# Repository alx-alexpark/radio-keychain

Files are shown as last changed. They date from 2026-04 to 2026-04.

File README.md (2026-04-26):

# radio-keychain
A fully-functional FM receiver in a 3x3cm footprint, perfect for a keychain.

It uses the connected headphones as an antenna, and is powered off a CR2032 coin cell. The FM tuner used is the Si4702, which supports the 76-108MHz frequency range.

Based on the CH32v003, this radio runs on RISC-V!

## Motivation
I love radio, and I wanted to make the tiniest keychain radio possible. I also thought it would be interesting to learn how radios work.

## How to use
First, connect a pair of headphones or an aux cable, this is your antenna. There are 4 buttons on the device, a volume up/down, and a frequency up/down. First, set the volume to a confortable level, and then use the frequency up/down buttons to step up and down 0.1MHz until you find a station. Then, enjoy listening to the station!

## Schematic and PCB
https://kicanvas.org/?repo=https://github.com/alx-alexpark/radio-keychain

## Zine
A5 - 1

## Bill of Materials

| Designator | Footprint | Quantity | Value | LCSC Part # |
|---|---|---|---|---|
| BT1 | BAT-SMD_MY-2032-12 | 1 | MY-2032-12 | [C964833](https://www.lcsc.com/product-detail/C964833.html) |
| C1, C6 | 0402 | 2 | 100nF | [C1525](https://www.lcsc.com/product-detail/C1525.html) |
| C2 | 0402 | 1 | 100pF | [C1546](https://www.lcsc.com/product-detail/C1546.html) |
| C3, C4 | 0603 | 2 | 0.47uF | [C1623](https://www.lcsc.com/product-detail/C1623.html) |
| C5, C7, C8 | 0603 | 3 | 1uF | [C1592](https://www.lcsc.com/product-detail/C1592.html) |
| C9 | 0402 | 1 | 22nF | [C1532](https://www.lcsc.com/product-detail/C1532.html) |
| CN1 | PJ-320D | 1 | PJ-320D | [C431535](https://www.lcsc.com/product-detail/C431535.html) |
| D1 | 0402 | 1 | LED | [C2286](https://www.lcsc.com/product-detail/C2286.html) |
| FB1, FB2 | 0603 | 2 | BLM18BD252SN1D | [C77668](https://www.lcsc.com/product-detail/C77668.html) |
| J1 | PinHeader_1x03_P2.54mm_Vertical | 1 | Conn_01x03_Pin | — |
| L1 | 0603 | 1 | LQW18ANR27J00D | [C98093](https://www.lcsc.com/product-detail/C98093.html) |
| OSC1 | CRYSTAL-SMD_4P-L3.2-W2.5-BL | 1 | SX2M32_768KM20F30TNN | [C2901603](https://www.lcsc.com/product-detail/C2901603.html) |
| R1, R2, R3, R4, R5, R6 | 0603 | 6 | 10k | [C25804](https://www.lcsc.com/product-detail/C25804.html) |
| R10, R9 | 0402 | 2 | 2k | [C4109](https://www.lcsc.com/product-detail/C4109.html) |
| R11 | 0402 | 1 | 330 | [C25104](https://www.lcsc.com/product-detail/C25104.html) |
| R7, R8 | 0402 | 2 | 2.2k | [C25879](https://www.lcsc.com/product-detail/C25879.html) |
| SW1, SW2, SW3, SW4 | SW-SMD_4P-L4.2-W3.3-P2.15-LS5.1 | 4 | SW_Push_45deg | [C455282](https://www.lcsc.com/product-detail/C455282.html) |
| SW5 | SW-SMD_MST22D18G2 | 1 | K3-2235S-F1 | [C223858](https://www.lcsc.com/product-detail/C223858.html) |
| U1 | QFN-20-1EP_3x3mm_P0.4mm_EP1.65x1.65mm | 1 | CH32V003F4U6 | [C5299908](https://www.lcsc.com/product-detail/C5299908.html) |
| U2 | QFN-28_4x4mm_P0.5mm | 1 | TPA6130A2RTJR | [C130046](https://www.lcsc.com/product-detail/C130046.html) |
| U3 | MPS_QFN-16_3x3mm_P0.5mm | 1 | SI4702-C19-GMR | [C2155666](https://www.lcsc.com/product-detail/C2155666.html) |

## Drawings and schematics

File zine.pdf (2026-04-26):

# Keychain Radio

### By Alex Park (18, TX)

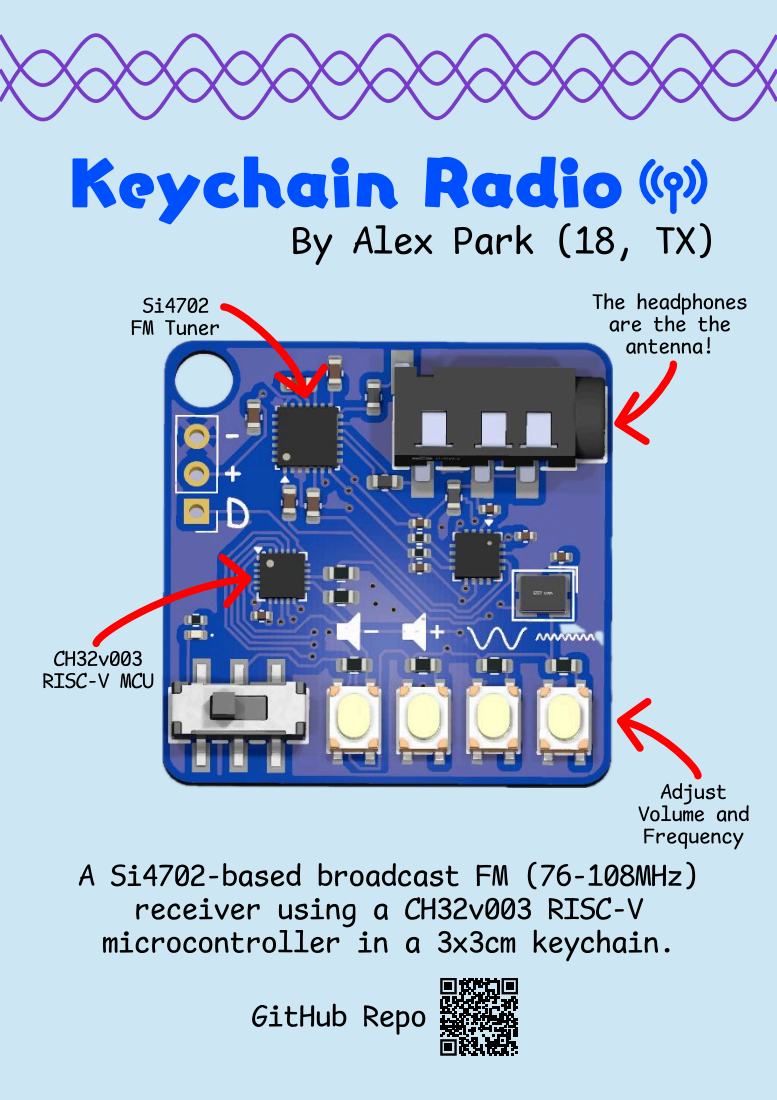
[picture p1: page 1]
Si4702 FM Tuner; CH32v003 RISC-V MCU; Adjust; Volume and Frequency; GitHub Repo

The headphones
are the the
antenna!

A Si4702-based broadcast FM (76-108MHz)
receiver using a CH32v003 RISC-V
microcontroller in a 3x3cm keychain.

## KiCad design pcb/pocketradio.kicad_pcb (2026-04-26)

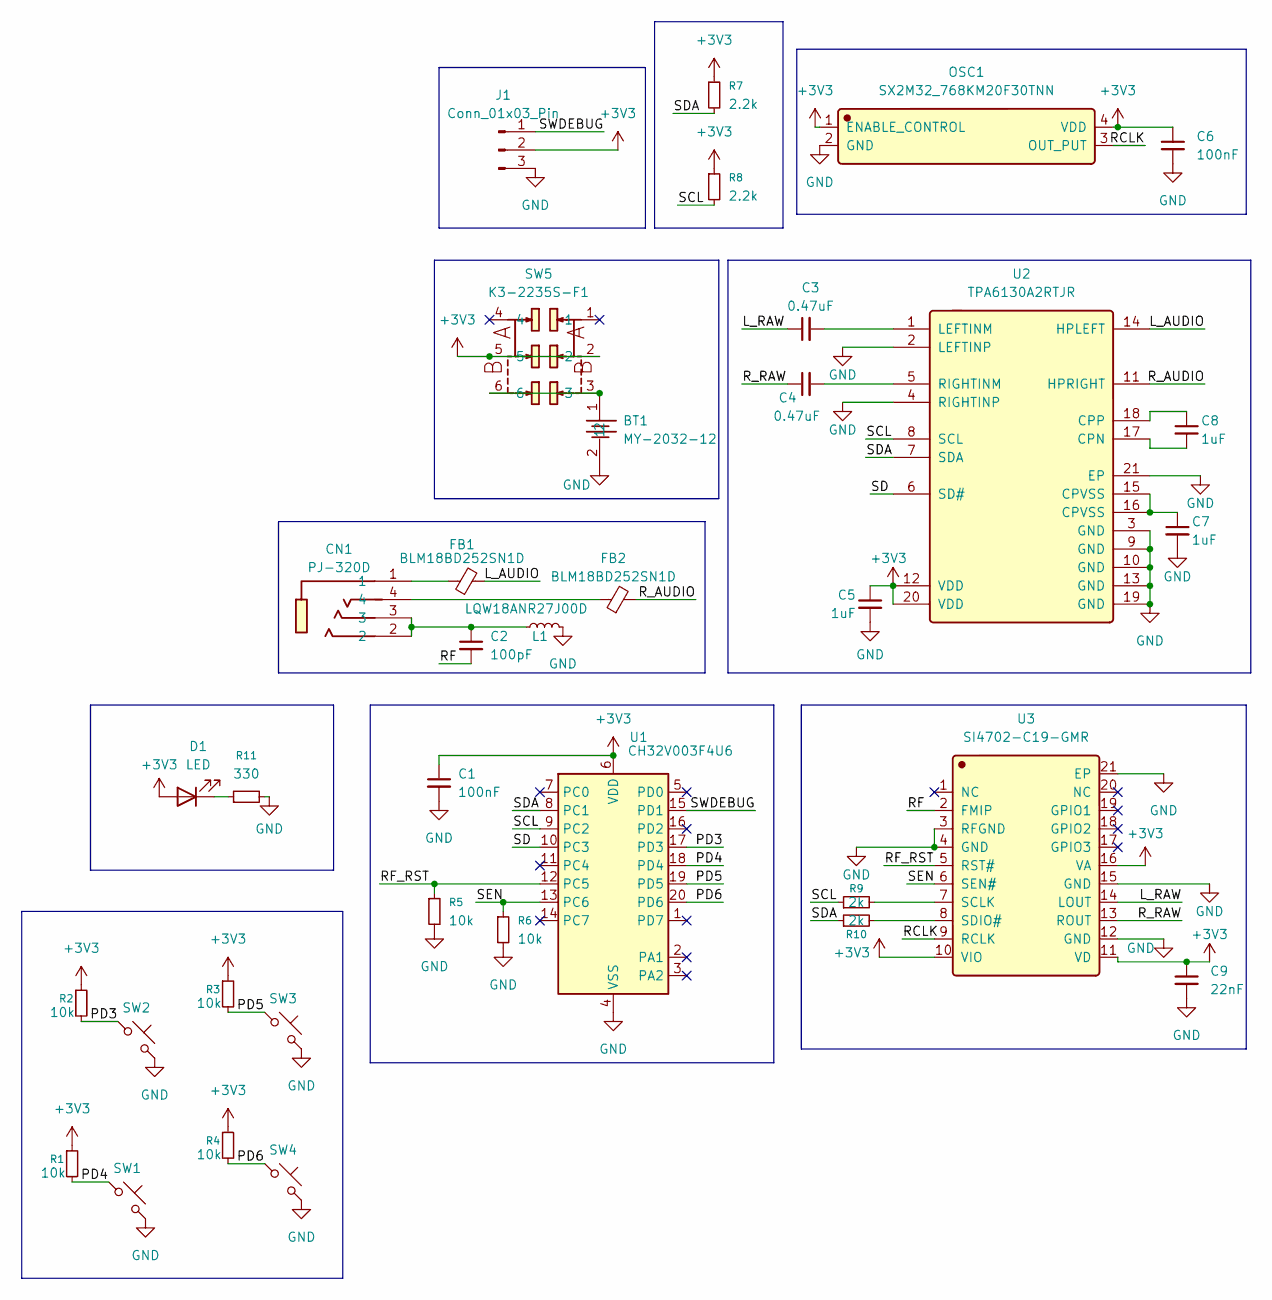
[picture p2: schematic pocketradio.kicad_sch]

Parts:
BT1: MY-2032-12; BAT-SMD_MY-2032-12; Manufacturer Part MY-2032-12; LCSC C964833
C1, C6: 100nF; C_0402_1005Metric; LCSC Part C1525
C2: 100pF; C_0402_1005Metric; LCSC Part C1546
C3, C4: 0.47uF; C_0603_1608Metric; LCSC Part C1623
C5, C7, C8: 1uF; C_0603_1608Metric; LCSC Part C1592
C9: 22nF; C_0402_1005Metric; LCSC Part C1532
CN1: PJ-320D; Manufacturer Part PJ-320D; LCSC C431535
D1: LED; LED_0402_1005Metric; LCSC Part C2286
FB1, FB2: BLM18BD252SN1D; L_0603_1608Metric; LCSC Part C77668
J1: Conn_01x03_Pin; PinHeader_1x03_P2.54mm_Vertical
L1: LQW18ANR27J00D; L_0603_1608Metric; LCSC Part C98093
OSC1: SX2M32_768KM20F30TNN; CRYSTAL-SMD_4P-L3.2-W2.5-BL; Manufacturer Part SX2M32.768KM20F30TNN; LCSC C2901603
R1, R2, R3, R4, R5, R6: 10k; R_0603_1608Metric; LCSC Part C25804
R7, R8: 2.2k; C_0402_1005Metric; LCSC Part C25879
R9, R10: 2k; R_0402_1005Metric; LCSC Part C4109
R11: 330; R_0402_1005Metric; LCSC Part C25104
SW1, SW2, SW3, SW4: SW_Push_45deg; SW-SMD_4P-L4.2-W3.3-P2.15-LS5.1; LCSC Part C455282
SW5: K3-2235S-F1; SW-SMD_MST22D18G2; Manufacturer Part K3-2235S-F1; LCSC C223858
U1: CH32V003F4U6; QFN-20-1EP_3x3mm_P0.4mm_EP1.65x1.65mm; LCSC C5299908
U2: TPA6130A2RTJR; QFN-28_4x4mm_P0.5mm; Manufacturer Part TPA6130A2RTJR; LCSC C130046
U3: SI4702-C19-GMR; MPS_QFN-16_3x3mm_P0.5mm; Manufacturer Part SI4702-C19-GMR; LCSC C2155666

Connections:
+3V3: C1.1, C5.1, C6.1, C9.1, D1.2 (A), J1.2, OSC1.1 (ENABLE_CONTROL), OSC1.4 (VDD), R1.1, R2.1, R3.1, R4.1, R7.1, R8.1, SW5.2, SW5.5, U1.6 (VDD), U2.12 (VDD), U2.20 (VDD), U3.10 (VIO), U3.11 (VD), U3.16 (VA)
/L_AUDIO: FB1.2, U2.14 (HPLEFT)
/L_RAW: C3.1, U3.14 (LOUT)
/PD3: R2.2, SW2.1, U1.17 (PD3)
/PD4: R1.2, SW1.1, U1.18 (PD4)
/PD5: R3.2, SW3.1, U1.19 (PD5)
/PD6: R4.2, SW4.1, U1.20 (PD6)
/RCLK: OSC1.3 (OUT_PUT), U3.9 (RCLK)
/RF: C2.2, U3.2 (FMIP)
/RF_RST: R5.1, U1.12 (PC5), U3.5 (RST#)
/R_AUDIO: FB2.2, U2.11 (HPRIGHT)
/R_RAW: C4.1, U3.13 (ROUT)
/SCL: R8.2, R9.1, U1.9 (PC2), U2.8 (SCL)
/SD: U1.10 (PC3), U2.6 (SD#)
/SDA: R7.2, R10.1, U1.8 (PC1), U2.7 (SDA)
/SEN: R6.1, U1.13 (PC6), U3.6 (SEN#)
/SWDEBUG: J1.1, U1.15 (PD1)
GND: BT1.2, C1.2, C5.2, C6.2, C7.2, C9.2, J1.3, L1.2, OSC1.2 (GND), R5.2, R6.2, R11.2, SW1.2, SW2.2, SW3.2, SW4.2, U1.4 (VSS), U1.21 (VSS), U2.2 (LEFTINP), U2.3 (GND), U2.4 (RIGHTINP), U2.9 (GND), U2.10 (GND), U2.13 (GND), U2.19 (GND), U2.21 (EP), U3.3 (RFGND), U3.4 (GND), U3.12 (GND), U3.15 (GND), U3.21 (EP)
unnamed: BT1.1, SW5.3, SW5.6
unnamed: C2.1, CN1.2, CN1.3, L1.1
unnamed: C7.1, U2.15 (CPVSS), U2.16 (CPVSS)
unnamed: CN1.1, FB1.1
unnamed: CN1.4, FB2.1
unnamed: D1.1 (K), R11.1
unnamed: C8.2, U2.17 (CPN)
unnamed: C8.1, U2.18 (CPP)
unnamed: C3.2, U2.1 (LEFTINM)
unnamed: C4.2, U2.5 (RIGHTINM)
unnamed: R9.2, U3.7 (SCLK)
unnamed: R10.2, U3.8 (SDIO#)

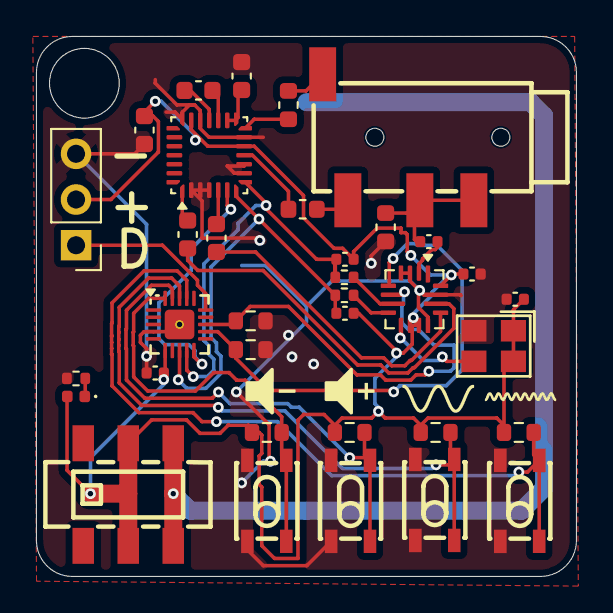
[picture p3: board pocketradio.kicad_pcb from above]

Board: 2 copper layers, 30.0 x 30.0 mm, 36 parts (1 on the bottom side), 30 nets.

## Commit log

2026-04-05 lots of stuff
    [pocketradio.kicad_pcb, pocketradio.kicad_sch]
2026-04-07 power LED
    [pocketradio.kicad_pcb, pocketradio.kicad_sch]
2026-04-07 recheck audio jack pinou
    [pocketradio.kicad_pcb, pocketradio.kicad_sch]
2026-04-26 change a few things
    [pocketradio.kicad_pcb, pocketradio.kicad_sch]
2026-04-26 Add LCSC product links to BOM
    [bom.csv]
2026-04-26 Append BOM table to README
2026-04-26 Link LCSC part numbers directly in BOM table
2026-04-26 reorganize files
    [pocketradio.kicad_pcb, pocketradio.kicad_sch]
2026-04-26 move folder
    [bom.csv, positions.csv]
